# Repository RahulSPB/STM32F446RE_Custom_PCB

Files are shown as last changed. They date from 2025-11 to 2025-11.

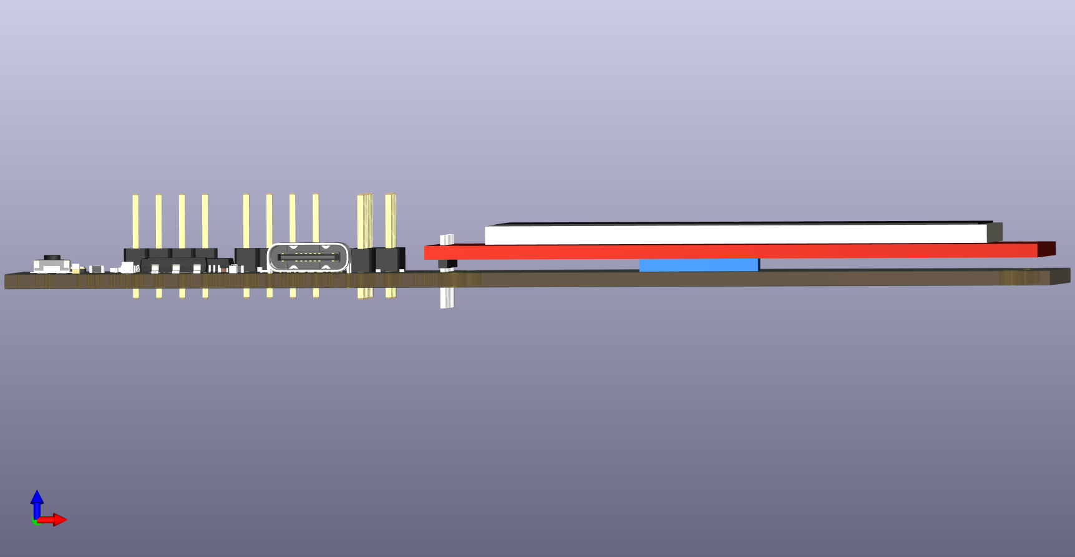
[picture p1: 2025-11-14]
documentation/pcb_3d_renders/side_view.png

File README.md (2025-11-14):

---

# **STM32F446RE – Custom 4-Layer Development Board**

A custom-designed development board built around the **STM32F446RE** microcontroller, featuring stable power architecture, clean signal routing, multiple communication interfaces, and onboard peripherals for embedded systems development.

---

## **📌 Overview**

This project contains the complete hardware design for a **4-layer STM32F446RE development board**, built for firmware experimentation, sensor interfacing, and peripheral testing.
The board includes a solid ground plane, dedicated power plane, USB-C input, ESD protection, and connectors for UART, I²C, SPI, and SWD.

This repository includes:

* KiCad source files
* Schematic PDF
* Fabrication-ready Gerbers
* 3D renders
* Board overview and design notes

---

## **🧠 Key Features**

### **Microcontroller**

* STM32F446RE (Cortex-M4 @ 180 MHz)
* 512 KB Flash, 128 KB SRAM
* Full peripheral support: UART, SPI, I²C, ADC, Timers, DMA, GPIO

### **Clocking**

* High-Speed External Oscillator (HSE)
* Crystal placed with proper layout guidelines

### **Power System**

* USB-C power input
* AMS1111-3.3 LDO (VBUS → 3.3V)
* 5V rail available for USB
* Decoupling caps at every VDD pin
* Ferrite bead for noise filtering
* Polyfuse protection on VBUS
* Power LED indicator

### **Connectivity**

* **UART** – 4-pin header
* **I²C** – 4-pin header
* **SPI** – 10-pin header
* **SWD** – 4-pin debug/programming header
* Onboard **Si7021** temp/humidity sensor (I²C)
* LCD interface for 16×2 / 20×4 displays

---

## **🔧 PCB Stackup & Layout**

### **4-Layer Stackup**

* **Layer 1 (Top):** Signal
* **Layer 2:** Solid Ground Plane
* **Layer 3:** Power Plane (3.3V, 5V, VBUS islands)
* **Layer 4 (Bottom):** Signal

### **Routing Strategy**

* 0.3 mm trace width for general signals
* 0.5–0.6 mm for power & ground
* High-frequency noise minimized with ferrite bead
* Stitching vias across ground and power areas
* VBUS isolated to regulator & USB-C region

---

## **📁 Repository Structure**

```
stm32f446re_custom_pcb/
│
├── hardware/
│   ├── kicad_project/          # Main KiCad project files
│   ├── gerbers/                # Gerber files for fabrication
│   └── gerbers.zip             # Fabrication-ready ZIP
│   
├── documentation/
│   ├── schematic.pdf           # Full schematic
│   ├── pcb_3d_renders/         # 3D images of the PCB
│   └── board_overview.md       # Detailed design description
│
└── README.md                   # You are here
```

---

## **🛠 Tools Used**

* KiCad
* EasyEDA (optional early drafts)
* 3D Viewer & Gerber viewer
* USB-C reference design
* ST AN2606 / Datasheet guidelines

---

## **📐 Getting the Files Manufactured**

1. Download **gerbers.zip**
2. Upload to PCBWay / JLCPCB / OSHPark
3. Select **4-layer PCB**
4. Use default stackup unless otherwise stated
5. Confirm drill sizes & clearances

---

## **📸 Preview**

Screenshots of 3D renders:
(Add your `top_view.png`, `bottom_view.png`, etc. here)

```
documentation/pcb_3d_renders/
│── top_view.png
│── bottom_view.png
│── angled_view.png
```

---

## **📎 Notes**

* Boot0 is set via pull-down resistor (no switch)
* NRST uses a push-button reset switch
* Power, ground, and critical lines follow recommended ST layout guidelines
* Board is designed for HAL-based STM32 firmware development

---

## **📧 Contact**

If you want a contact section at the bottom:

```
Developer: Rahul Bagathi  
Email: Bagathi_ug_24@ei.nits.ac.in 
LinkedIn:https://www.linkedin.com/in/bagathi-rahul-b27411371 
GitHub: https://github.com/RahulSPB

```

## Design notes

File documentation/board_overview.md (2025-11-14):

# **STM32F446RE – 4-Layer Custom Development Board**

### **Board Overview**

This custom 4-layer PCB is designed around the **STM32F446RE** microcontroller for reliable embedded systems development, sensor interfacing, and firmware experimentation. The design emphasizes clean power delivery, low-noise routing, and robust peripheral expansion, following industry-standard PCB practices.

---

## **Core Specifications**

### **Microcontroller**

* **STM32F446RE** (ARM Cortex-M4 @ 180 MHz)
* 512 KB Flash, 128 KB SRAM
* Rich peripheral set: UART, I²C, SPI, ADC, Timers, DMA, GPIO, etc.

### **Clocking**

* **High-Speed External Oscillator (HSE)** for accurate system timing
* Crystal placed with proper guard traces and decoupling

### **Boot & Reset**

* **BOOT0 pulled down via resistor** (no switch used)
* **NRST** connected to a classic push-button reset switch
* Reset line filtered and referenced cleanly to ground

---

## **Power Architecture**

### **Input & Regulation**

* **USB-C port** used as primary power input
* **AMS1117-3.3V LDO** converts VBUS → 3.3V
* 5V rail available for USB and related peripherals
* VBUS kept isolated to a small controlled island feeding the regulator

### **Filtering & Stability**

* Decoupling capacitors placed at every VDD pin (0.1µF + bulk caps)
* **Ferrite bead** used for high-frequency noise suppression
* **Polyfuse** protection at USB-C input
* Clean ground return paths ensured through layer stackup

### **ESD Protection**

* ESD diode protection on USB-C and sensitive I/O lines
* Safe spacing and return path planning to support surge handling

### **Indicators**

* **Power LED** connected to 3.3V rail for power-on indication

---

## **Connectivity & Interfaces**

### **Communication Headers**

Modular connectors for peripheral expansion:

* **UART** – 4-pin header
* **I²C** – 4-pin header
* **SPI** – 10-pin header
* **SWD** – 4-pin programming/debug header

All connectors arranged with consistent VCC/GND ordering for easy interfacing.

### **On-Board Peripherals**

* **Si7021** Temperature & Humidity Sensor (I²C)
* **LCD Interface** (compatible with 16x2 / 20x4 displays)
* Clean routing of sensor and display lines for minimal noise

---

## **PCB Layout & Stackup**

### **Layer Stack**

* **Layer 1 (Top Layer):** Signal routing
* **Layer 2 (Inner Layer 1):** **Solid Ground Plane** (continuous GND reference)
* **Layer 3 (Inner Layer 2):** **Dedicated Power Plane**

  * Independent regions for **3.3V**, **5V**, and **VBUS**
  * 3.3V used across most of the board
  * 5V confined to USB-related sections
  * VBUS limited to the regulator and USB-C island
* **Layer 4 (Bottom Layer):** Signal routing

### **Routing Rules**

* **0.3 mm trace width** for standard signal lines
* **0.5–0.6 mm traces** for power and ground
* Controlled routing to minimize crosstalk and ensure integrity

### **Via Strategy**

* **Stitching vias** placed across all ground and power areas
* Ground plane stitched densely to improve return paths
* Power planes also stitched for low-impedance delivery
* No unnecessary connections to planes — only GND and power vias used

This ensures clean current flow, reduced ground bounce, and improved EMI performance.

---

## **Design Goals**

* Stable power distribution
* Low-noise routing for digital & analog peripherals
* Flexible expansion via UART, I²C, SPI, and SWD
* Professional-grade 4-layer design suitable for real firmware work
* Robustness through ESD protection, filtering, and proper decoupling

---

## **Repository Contents**

* KiCad project files (`.kicad_sch`, `.kicad_pcb`, `.kicad_pro`)
* Schematic PDF
* Gerber & drill files + ZIP for fabrication
* 3D renders of the board
* Board documentation and layout notes

---

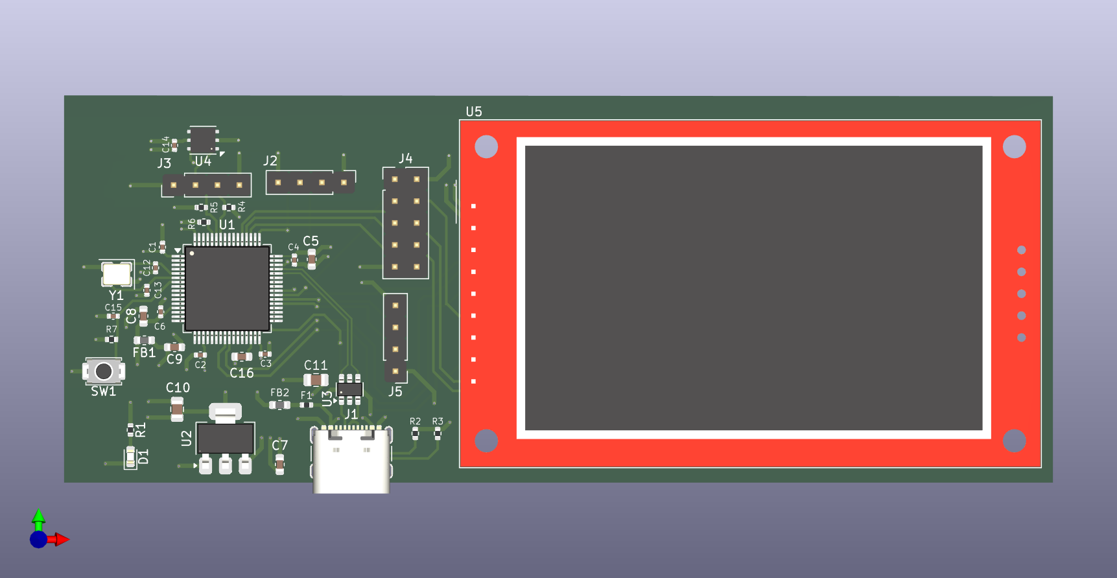
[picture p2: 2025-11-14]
documentation/pcb_3d_renders/top_view.png

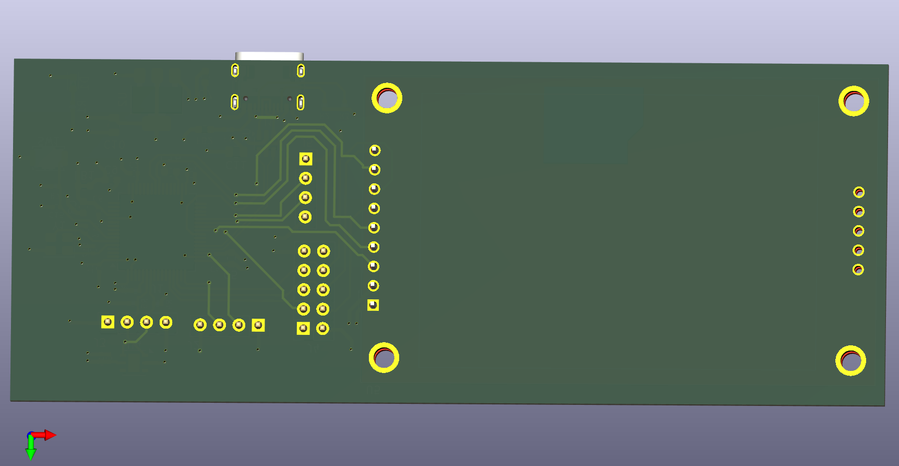
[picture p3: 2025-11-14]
documentation/pcb_3d_renders/bottom_view.png

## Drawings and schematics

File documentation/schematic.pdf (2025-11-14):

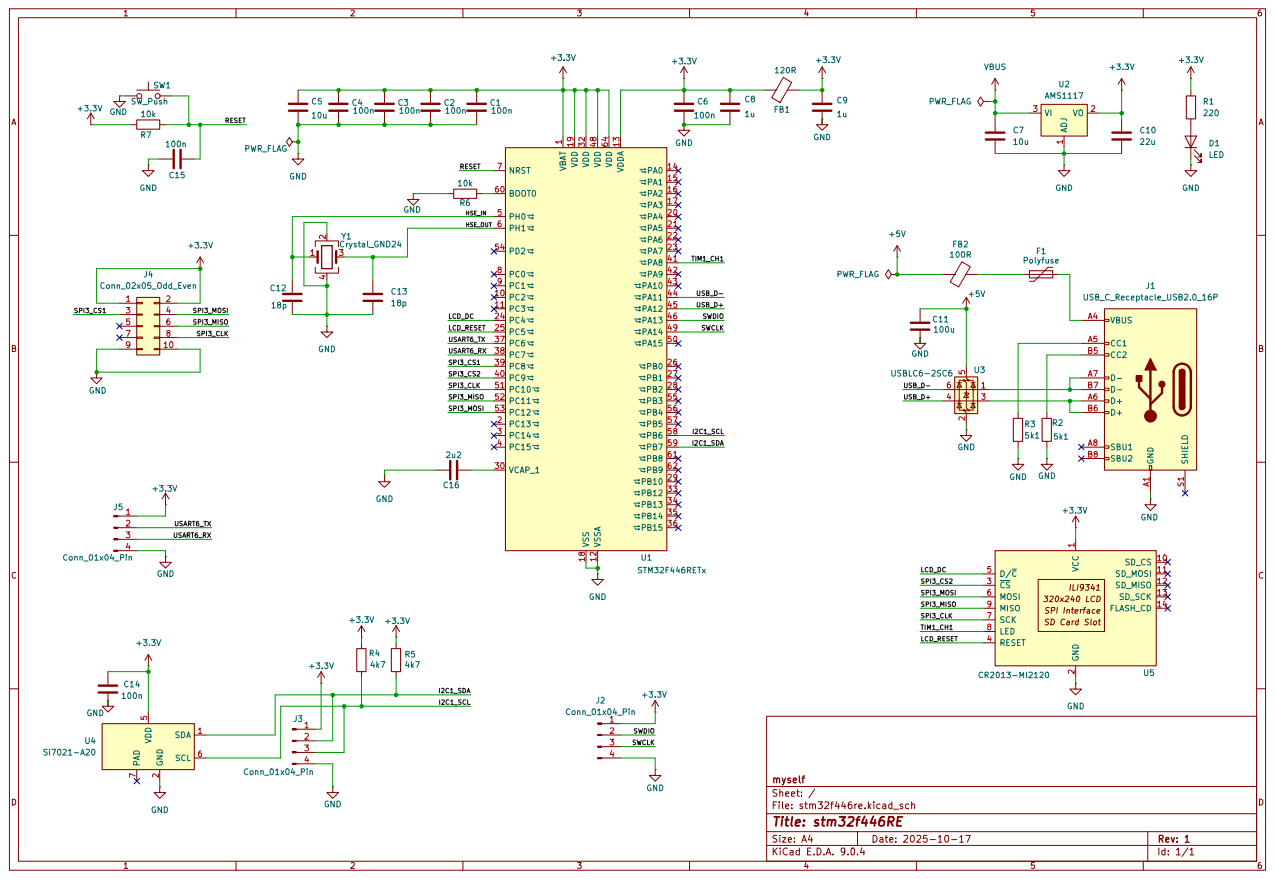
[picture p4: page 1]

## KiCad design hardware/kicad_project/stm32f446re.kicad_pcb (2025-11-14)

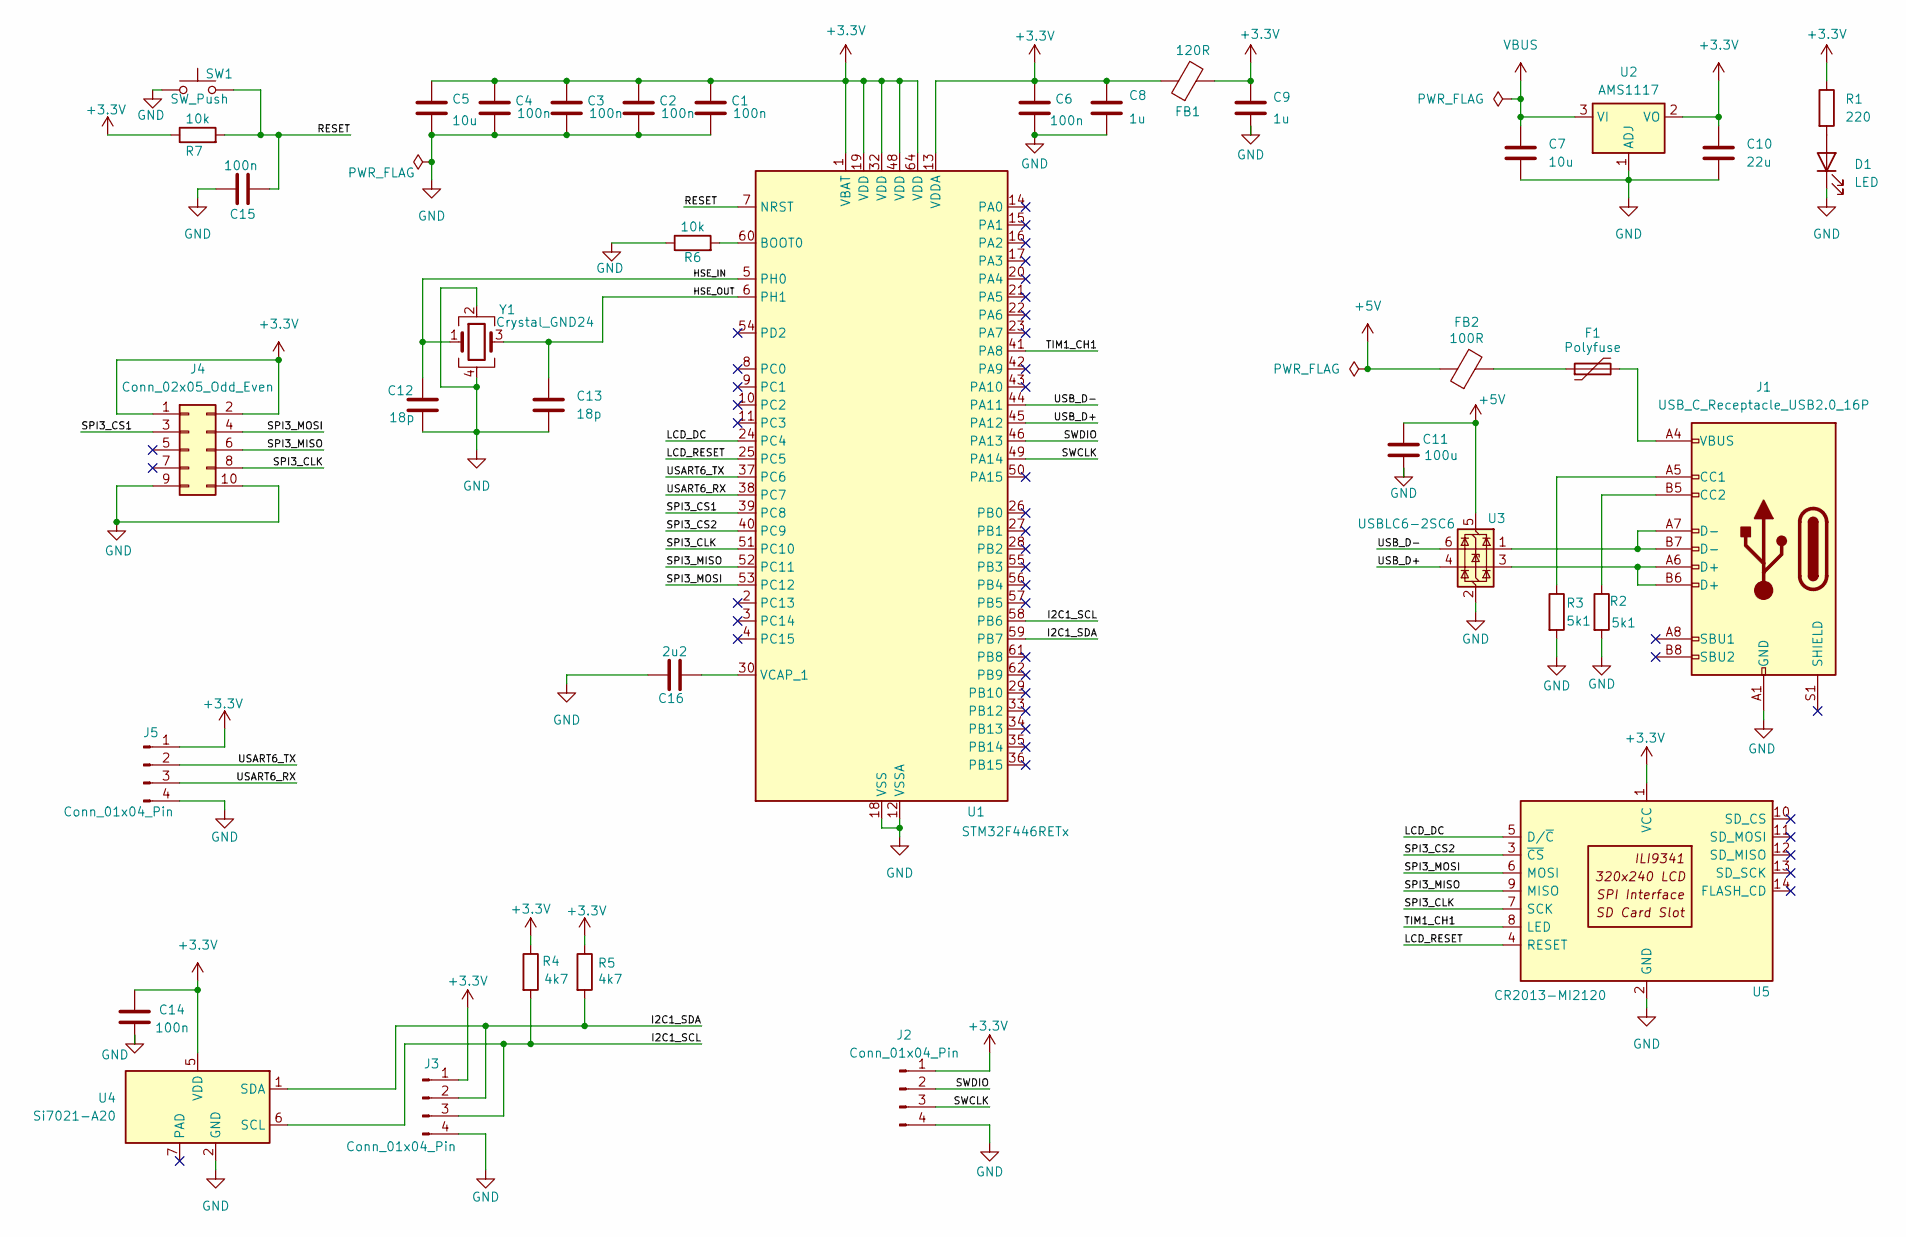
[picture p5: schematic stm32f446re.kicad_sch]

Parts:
C1, C2, C3, C4, C6, C14, C15: 100n; C_0402_1005Metric
C5, C7: 10u; C_0603_1608Metric
C8, C9: 1u; C_0603_1608Metric
C10: 22u; C_0805_2012Metric
C11: 100u; C_0805_2012Metric
C12, C13: 18p; C_0402_1005Metric
C16: 2u2; C_0603_1608Metric
D1: LED; LED_0603_1608Metric
F1: Polyfuse; Fuse_0402_1005Metric
FB1: 120R; L_0603_1608Metric
FB2: 100R; L_0603_1608Metric
J1: USB_C_Receptacle_USB2.0_16P; USB_C_Receptacle_GCT_USB4105-xx-A_16P_TopMnt_Horizontal
J2, J3, J5: Conn_01x04_Pin; PinHeader_1x04_P2.54mm_Vertical
J4: Conn_02x05_Odd_Even; PinHeader_2x05_P2.54mm_Vertical
R1: 220; R_0402_1005Metric
R2, R3: 5k1; R_0402_1005Metric
R4, R5: 4k7; R_0402_1005Metric
R6, R7: 10k; R_0402_1005Metric
SW1: SW_Push; SW_Push_SPST_NO_Alps_SKRK
U1: STM32F446RETx; LQFP-64_10x10mm_P0.5mm
U2: AMS1117; SOT-223-3_TabPin2
U3: USBLC6-2SC6; SOT-23-6
U4: Si7021-A20; DFN-6-1EP_3x3mm_P1mm_EP1.5x2.4mm
U5: CR2013-MI2120
Y1: Crystal_GND24; Crystal_SMD_3225-4Pin_3.2x2.5mm

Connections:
+3.3V: C1.1, C2.1, C3.1, C4.1, C5.1, C6.1, C8.1, C9.1, C10.1, C14.1, FB1.1, FB1.2, J2.1, J3.1, J4.1, J4.2, J5.1, R1.1, R4.1, R5.1, R7.1, U1.1 (VBAT), U1.13 (VDDA), U1.19 (VDD), U1.32 (VDD), U1.48 (VDD), U1.64 (VDD), U2.2 (VO), U4.5 (VDD), U5.1 (VCC)
+5V: C11.1, FB2.1, U3.5 (VBUS)
/HSE_IN: C12.1, U1.5 (PH0), Y1.1
/HSE_OUT: C13.1, U1.6 (PH1), Y1.3
/I2C1_SCL: J3.3, R4.2, U1.58 (PB6), U4.6 (SCL)
/I2C1_SDA: J3.2, R5.2, U1.59 (PB7), U4.1 (SDA)
/LCD_DC: U1.24 (PC4), U5.5 (D/~C)
/LCD_RESET: U1.25 (PC5), U5.4 (RESET)
/RESET: C15.2, R7.2, SW1.2, U1.7 (NRST)
/SPI3_CLK: J4.8, U1.51 (PC10), U5.7 (SCK)
/SPI3_CS1: J4.3, U1.39 (PC8)
/SPI3_CS2: U1.40 (PC9), U5.3 (~CS)
/SPI3_MISO: J4.6, U1.52 (PC11), U5.9 (MISO)
/SPI3_MOSI: J4.4, U1.53 (PC12), U5.6 (MOSI)
/SWCLK: J2.3, U1.49 (PA14)
/SWDIO: J2.2, U1.46 (PA13)
/TIM1_CH1: U1.41 (PA8), U5.8 (LED)
/USART6_RX: J5.3, U1.38 (PC7)
/USART6_TX: J5.2, U1.37 (PC6)
/USB_D+: U1.45 (PA12), U3.4 (I/O2)
/USB_D-: U1.44 (PA11), U3.6 (I/O1)
GND: C1.2, C2.2, C3.2, C4.2, C5.2, C6.2, C7.2, C8.2, C9.2, C10.2, C11.2, C12.2, C13.2, C14.2, C15.1, C16.1, D1.1 (K), J1.A1 (GND), J1.A12 (GND), J1.B1 (GND), J1.B12 (GND), J2.4, J3.4, J4.9, J4.10, J5.4, R2.2, R3.2, R6.1, SW1.1, U1.12 (VSSA), U1.18 (VSS), U1.31 (VSS), U1.47 (VSS), U1.63 (VSS), U2.1 (ADJ), U3.2 (GND), U4.2 (GND), U5.2 (GND), Y1.2, Y1.4
unnamed: D1.2 (A), R1.2
unnamed: F1.1, FB2.2
unnamed: F1.2, J1.A4 (VBUS), J1.A9 (VBUS), J1.B4 (VBUS), J1.B9 (VBUS)
unnamed: J1.A5 (CC1), R3.1
unnamed: J1.B5 (CC2), R2.1
unnamed: J1.A6 (D+), J1.B6 (D+), U3.3 (I/O2)
unnamed: J1.A7 (D-), J1.B7 (D-), U3.1 (I/O1)
unnamed: R6.2, U1.60 (BOOT0)
unnamed: C16.2, U1.30 (VCAP_1)
VBUS: C7.1, U2.3 (VI)

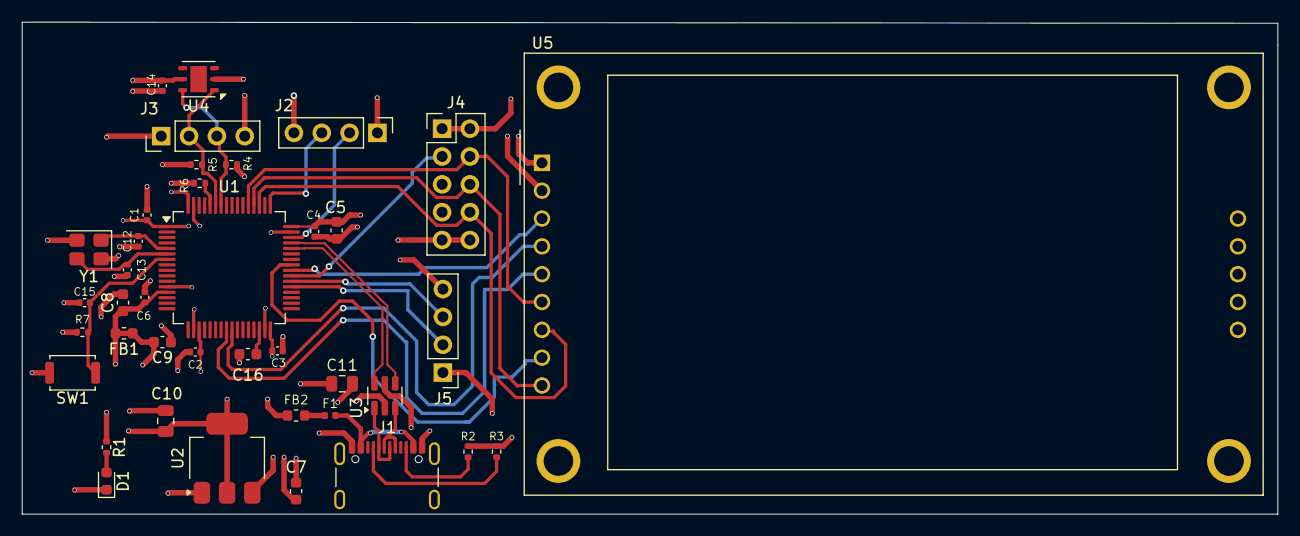
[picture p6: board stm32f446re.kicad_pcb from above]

Board: 4 copper layers, 114.6 x 44.9 mm, 39 parts (0 on the bottom side), 32 nets.
